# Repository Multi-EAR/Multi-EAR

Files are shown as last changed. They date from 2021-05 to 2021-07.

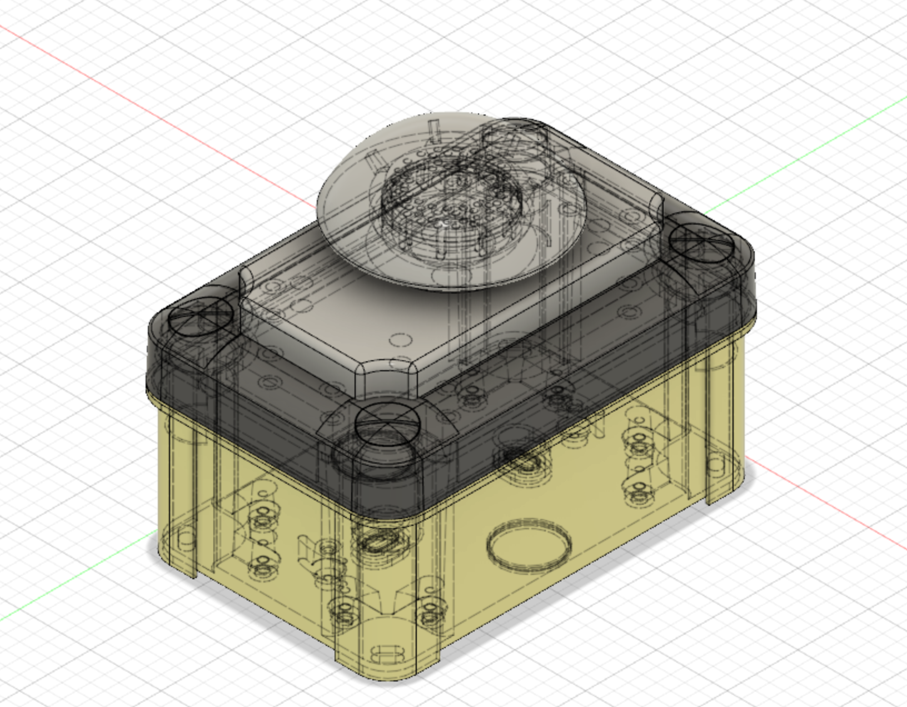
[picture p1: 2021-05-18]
Casing/Small/Small_casing.png

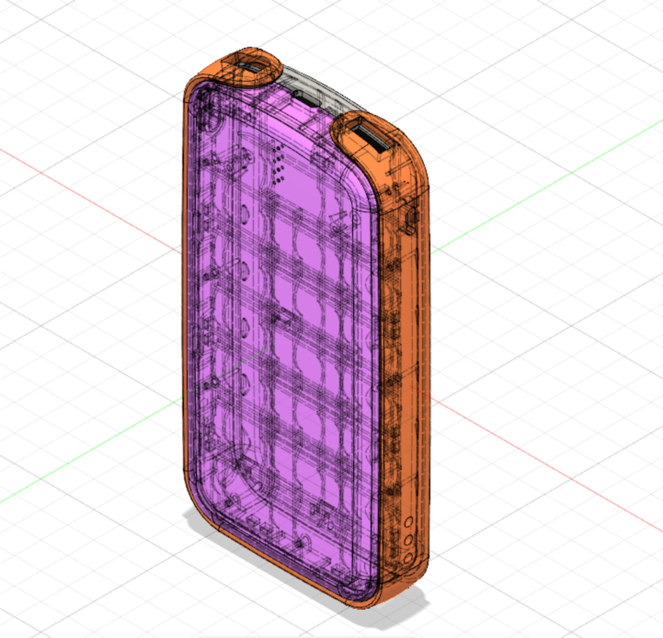
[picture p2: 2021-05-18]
Casing/Solar/V75 Battery/V75.png

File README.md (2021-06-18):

# Multi-EAR

The Multi Earth and Atmospheric data Recorder (Multi-EAR); a mobile low-cost multidiciplinairy sensor platform for scientific monitoring of earth and atmosphere.

<hr/>

A collabarotive project between the Royal Netherlands Meteorological Institute (KNMI) and Delft University of Technology (TU Delft).

<sub><sup>Auke Barnhoorn (TUD), Jens van den Berg (TUD), Olivier den Ouden (KNMI/TUD), Pieter Smets (TUD/KNMI), Laslo Evers (TUD/KNMI), Jelle Assink (KNMI), Elliot Donata (Min. IenW), Gijs Schouwenberg (Min. IenW)</sup></sub>

<hr/>

The project has been awarded the 'Digitaliserings-fonds en Ontwikkeling' research grand by the Netherlands Ministry of Infrastructure and Water Management and an 'Innovation' grand by the Delft University of Technology. 

The Multi-EAR is an extension of the INFRA-EAR (\cite{den2020low}), which is a multidisciplinary sensor platform for the monitoring of geophysical parameters, and specially designed to fit a Wandering Albatros. Such requirements, and thus dimensional restrictions, were not applicable by the design and development of the Multi-EAR. The project aims to develop, based on earlier recommendations, a multidisciplinary mobile sensor platform to complement the existing high-fidelity monitoring network. Due to its digital design, the sensor platform can readily be integrated with existing geophysical data infrastructures and be embedded in geophysical data analysis. The small dimensions and low-cost price per unit allow for unconventional, experimental designs, for example, high-density spatial sampling or deployment on moving measurement platforms. Moreover, such deployments can complement existing high-fidelity geophysical sensor networks. To include the Multi-EAR within existing monitoring networks, a Technology Readiness Level (TRL) of 8 is needed (Figure \ref{fig:8}).

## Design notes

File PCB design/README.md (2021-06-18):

# Mobile platform design
### Circuit design

The platform of the Multi-EAR uses various digital Microelectromechanical sensors (MEMS) embedded on a Printed Circuit Board (PCB). A programmable microcontroller unit, embedded on the PCB, controls the sensor's sampling frequency, establishes the energy supply for the sensors, the data communication, and data storage.

The MEMS on the PCB are; two differential pressure sensor (to monitor infrasound), a 6-axis accelerometer/gyroscope, a 6-axis accelerometer/magnetometer, a barometric pressure sensor, a temperature/humidity sensor, microphones (to monitor audible sound), a GPS for location and timing purposes, and LoRa telecommunication for data exchange.

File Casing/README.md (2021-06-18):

# Casings

The protection of the PCB is done with a weather- and waterproof casing. The GPIO pins connect the RPi and the Multi-EAR. For insurance, they are as well connected by four screws on the corners. The casing exists of a pre-ordered polyethene case with an atmospheric dome on top. The RPi is connected to the casing, by a 3D-printed ground-plate, for direct coupling.

## Atmospheric dome
An atmospheric done is placed on top of the casing, fastened with screws and glue. The dome allows air to flow in and out of the casing, essential for the atmospheric measurements but deducts water to enter the casing. Figure \ref{fig:10} shows the 3D CAD design of the dome. Air can flow into the dome via the inlets on the side and top of the capture. This way, the dome enables airflow inside the casing but obstructs water. Whenever moisture becomes a problem, GoreTex air vents may be considered (\cite{den2020low}). Furthermore, the dome also prevents stagnation pressure, which may mask the differential pressure measurements (\cite{raspet2019new}).
 
## Casing designs
Two different casings are developed for the Multi-EAR (Appendix D). The smaller casing (\cite{SmallCasing})has a dimension of 130 x 85 x 115 mm (Figure \ref{fig:11}). The dome is placed on top of the transparent lid of the casing, while the two antennas are mounted to the side and the external power supply plug. The smaller casings are not fully autonomous, and it does not function without connection to an external power supply. Whenever powered, however, the Multi-EAR starts recording and collecting data, as pre-defined in the firmware.
 
The larger casings have a dimension of 240 x 191 x 130 mm (\cite{LargeCasing}) and includes a solar panel. These casings are designed to make the Multi-EAR completely autonomous. Again a polyethene case with the atmospheric dome on top is used. The GPS and LoRa antenna are connected to the outside of the casing and the ability to use external power.

## Antennae
The LoRa and GPS on the PCB are both connected to external antenna's. The antennae are passive LinX antennae (\cite{Linx}). The band with range is between 617MHz - 5 GHz. The classification of the antenna is a high-blade for optimal signal coverage. 
The polarization of the antennae is linear, and the radiation of signals omnidirectional. Moreover, the GPS on the PCB, and thus the antenna, is a GNSS receiver (\cite{GNS2301}) and thus compatible with GPS (global system), GLONASS (Russian navigational system), Beidou (Chinese navigational system), Galileo (European navigational system). Therefore the PCB has perfect coverage.   
The antennae are mounted to the outside of the casings and connected to the MEMS of the GPS and LoRa by SMA extension cables (\cite{SMAcable}, Appendix D).

## External power supply
5W micro-USB connectors generate the external power supply. The cable is modified to ensure the complete protection of the casing. Moreover, the modification allows disconnecting the power supply from the outside without doing modifications within the casing.
Within the casing, the RPi is connected through Micro-USB with a female Amphenol connector (\cite{Amphenol}, Appendix D). This female connector is pinned to the outside of the casing. The male connector is directly connected to a 5W adaptor. The connection between male and female connectors is strong and weather/waterproof. Figure \ref{fig:pin} shows the 'three-pin layout of the Amphenol connectors.
 
## Autonomous system
The larger casings are equipped with a solar panel (\cite{VoltaicSolar}) and battery pack (\cite{VoltaicBattery}). These platforms can either be powered by an external power supply or by a battery pack. The battery pack is a V75 battery and is placed within the casing. It has an 'always-on mode; it can power, charge, and pass-through charging. The capacity is 19.200 mAh (71 Watt-Hours), and the output is 5V. 

The solar panel that charges the V75 battery pack is placed on top of the casing. The mounting allows modification of sunlight's angle. The panel is waterproof and has a 9Watt, 6V output. 

## Energy analysis

To determine whether the autonomous system can monitor continuously, thorough energy analysis is performed. The energy analysis is divided into (1) the energy consumption by the PCB and RPi during concurrently continuous monitoring and the (2) power supply by the solar panel and battery capacity to survive the evenings.

First, the energy consumption by the RPi. Assuming continuous measurements and thus power supply, the RPi will use approximately 1 Watt per hour, which adds to a maximum of 24 Watt per day. 

The consumption by the PCB depends on the low-energy MEMS sensors, which is marginal compared to other monitoring devices. The power consumption is estimated at around 5W per day, which is 0.2 Watt per hour. 

Therefore, the total power consumption of the entire system is estimated to be approximately 29 Watt per day, which is 1.2 Watt per hour.

The V75 battery pack has a maximum capacity of 71 Watt. Without charging the battery pack, the monitoring system can be active for approximately 70 hours. During summer, the time between sunset and sunlight is approximately 6 hours. Therefore it is assumed the system will 'survive' the summer evenings. In winter, the nights are longer, and therefore the re-charging time of the battery is shorter. Moreover, thus the monitoring system is assumed to run out of power during these periods.

During the day, the battery pack needs to be charged while supplying the needed power for the monitoring system. To determine the expected charging energy of the solar panel, a thorough analysis is performed. For the analysis, the solar panel position is fixed to the Campus of the TU Delft. Based on the technical specifications of the 9 Watt solar panel and the expected sunlight at the Campus, energy analysis is calculated (\cite{SolarEnergy}). Figure \ref{fig:solar} shows the average energy output of the solar panel in Watt per day. Note that from March until September, the Solar panel provides enough power to run the system. Since enough power is provided for the monitoring system, the battery will be charged during the day. Within the winter months, however, the monitoring system will run out of power. The battery and solar panel will not provide sufficient power for continuous and concurrent monitoring.

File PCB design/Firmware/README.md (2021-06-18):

# Firmware

The communication between the microcontroller and MEMS on the PCB is either done by Inter-Integrated Circuit (I2C) or Serial Peripheral Interface (SPI) and depends on the sensor and personal preference. Both communication methods are bus protocols and allow for serial data transfer. However, SPI handles full-duplex communication, simultaneous communication between microcontroller and MEMS sensor, while I2C is half-duplex. Therefore, I2C has the option of clock stretching, and the communication is stopped whenever the MEMS sensor cannot send data. Besides, I2C has built-in features to verify the data communication (e.g., start/stop bit, acknowledgement of data). Although the I2C protocol is favourable, it requires more power. Moreover, the number of I2C ports on the microcontroller is limited. Therefore a mix of both SPI and I2C protocols is needed.

The microcontroller runs on self-made software, complementing the required manufacturers electrical and communication protocols. The software allows determining the sample time, sample frequency, and data storage of selected MEMS. The raw output of the digital MEMS sensors are stored as bits, and the microcontroller performs no data processing to save power consumption. 

The firmware, and thus the data acquisition, can be changed and updated on the microcontroller.

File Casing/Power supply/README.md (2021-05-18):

# External Power supply 

To power the RPi and Multi-EAR with an external power supply, a 5W adapter is used. One half of the adapter cable is soldered to the female amphenol connector, while the other half is soldered to the male amphenol connector. This way the external power supply of the Multi-EAR can be unplugged during storage. The amphenol connectors ensure a waterproof power supply.

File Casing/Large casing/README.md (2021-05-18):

# Small casing

## Bottomplate

## Atmospheric dome

## 3D printer

## External power supply

## Antenna

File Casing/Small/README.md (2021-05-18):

# Small casing

## Bottomplate

## Atmospheric dome

## 3D printer

## External power supply

## Antenna

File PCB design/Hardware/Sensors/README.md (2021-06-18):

# Sensors

## Sound sensors
The human audible sound spectrum is approximately between 20 to 20,000 Hz. Frequencies below 20 Hz or above 20 kHz are referred to as infrasound and ultrasound, respectively. The movement of large air volumes generates infrasound signals with amplitudes in millipascals' range to tens of pascals. Examples of infrasound sources include earthquakes, lightning, meteors, nuclear explosions, interfering oceanic waves and surf (\cite{campus2010worldwide}). Detection of infrasound depends on the signal's strength relative to the noise levels at a remote sensor (array), i.e., the signal-to-noise ratio. The signal strength depends, in turn, on the transmission loss that a signal experiences while propagating from source to receiver (\cite{waxler2019propagation}). Local wind noise conditions predominantly determine the noise (\cite{raspet2019new}), in addition to the sensor self-noise. Due to the presence of atmospheric waveguides and low absorption at the infrasonic frequency (\cite{sutherland2004atmospheric}), infrasonic signals can be detected at long distances from an infrasonic source. Assumed that the source levels are sufficiently high so that the long-range signal is above the ambient noise conditions on the receiver side, and the sensor is sensitive enough to detect the signal.

### Infrasound
The infrasonic wavefield is conventionally measured with pressure transducers since such scalar measurements are relatively easy to perform. Those measurements can either be performed by absolute or differential pressure sensors. An absolute pressure sensor consists of a sealed aneroid and a measuring cavity connected to the atmosphere. A pressure difference within the measuring cavity will deflect the aneroid capsule. The mechanical deflection is converted to a voltage (\cite{haak1996microbarograph}). The measurement principle of a differential infrasound sensor relies on the deflection of a compliant diaphragm, which is mounted on a cavity inside the sensor. The membrane deflects due to a pressure difference inside and outside the microphone, which occurs when a sound wave passes. A pressure equalization vent is part of the design to make the microphone insensitive to slowly varying pressure differences originating from long-period changes in weather conditions (\cite{ponceau2010low}).  

Various studies show sensor self-noise and sensitivity curves of infrasound sensors (\cite{ponceau2010low,merchant2015hyperion,slad2016chaparral,marty2019ims,nief2019new}). The IMS specifications state that the sensor self-noise should be at least 18 dB below the global low noise curves at 1 Hz (\cite{brown2014idc}), generated from global infrasound measurements using the IMS. Typical infrasound sensor networks, such as the IMS, use analogue sensors connected to a separate data logger to convert the measured voltage differences to a digital signal. The sensor's characteristic sensitivity determines the sensor resolution, i.e., the smallest difference that the sensor can detect. The resolution of the built-in analogue-to-digital converters (ADC) and the digitizing voltage range determine the datalogger's resolution. Current state-of-the-art data loggers have a 24-bit resolution. New infrasound sensor techniques involve digital outputs since the ADC conversion is realized inside the sensor (\cite{nief2017new,nief2019new}). 

The design of this instrument is based on the following requirements. The sensor should have a flat, linear response over a wide infrasonic frequency band, e.g., 0.05 - 10 Hz. The sensor should be sensitive to the range of pressure perturbations in this frequency band, ranging from millipascals to tens of pascals. Moreover, the sensor and logging components' self-noise should be below the ambient noise levels of the IMS (\cite{brown2014idc}). Taking this into account, the sensor requires as well to be low-cost (i.e., tens of dollars), small in dimensions (i.e., millimeter), and have a low energy consumption (i.e., milliampere). 

The measurement principle relies on the deflection of a diaphragm, which is mounted between two inlets. One inlet is connected to the atmosphere, while the other is connected to a cavity. The digital MEMS DLVR-F50D differential pressure sensor from All Sensors Inc (\cite{DLVR}) is used as a sensing element within the mini-MB. This sensor has a 16.5mm x 13.0mm x 7.3mm dimension and a linear response between $\pm$ 125 Pa and a maximum error band of $\pm 0.7$ Pa. A Wheatstone bridge senses the diaphragm's deflection by measuring the changes in the piezo-resistive elements attached to the diaphragm. The sensor's output is an analogue voltage, which is subsequently digitized by the built-in 14-bit ADC, offering a maximum resolution of $0.02$ Pa/count.

### Audible sound
For the monitoring of the audible sound spectrum, three ICS-40300 microphones are embedded on the PCB (\cite{ICS40300}). These microphones are low-noise, high SPL MEMS microphones with an extended low-frequency response. The frequency response can be extended from $6-20\text{k}$ Hz and has a flat response between $50-2500$ Hz. Thanks to this frequency range, combining the infrasound sensor and the microphones results in an excellent phase and amplitude characteristic within a broad frequency range (0.075 - 20k Hz). The maximum SPL level of the microphones is 130dB before the overload is reached. 

The measurements of the microphones are by default stored as RMS dB SPL level over the entire frequency range. Whenever an RPi is used as a datalogger, there is an option to store the entire time series recording.

## Meteorological sensors
The detectability of infrasound is directly linked to wind noise conditions and the atmosphere's stability in the infrasound sensor's surrounding since noise levels are increased when turbulence levels are high. Therefore, it is beneficial to have simultaneous measurements of the basic meteorological parameters, i.e., pressure, humidity and temperature. The sub-sections below describe the different meteorological measurements contained on the sensor platform.

### Barometer
The barometric pressure is sensed by the LPS33HW sensor (\cite{LPS33HW}). The measuring principle relies on piezo-resistive crystals. The atmospheric pressure applies a force to the sensor, which causes the crystals to vibrate. Whenever piezo-resisitve crystals have contact, or a force is applied to the, a small voltage is released.

The sensor design is analoge, using voltages to derive the geophysical units. However, this MEMS has an in-built 14-bits ADC. The ADC bits and the precision of the crystals determine the self-noise of the sensor. Whenever the self-noise is higher as the actual change in atmospheric pressure, it will not be resolved by the sensor. The manufacturer states that the relative error of the sensor is $\pm 0.1$hPa. However, the absolute error can be larger. Therefore a calibration need to be performed on these sensors, to remove the absolute error. \cite{den2020low} stated that after calibration the sensor can indeed have an accuracy of $\pm 0.1$ hPa.

### Temperature/Humidity
The SHT8x sensor measures the temperature and humidity at the PCB (\cite{SHT8x}). The SHT8x is a temperature and humidity sensor with a pin-type connector. This connector allows easy integration and replacement of the sensor. Furthermore, it allows for the best possible thermal coupling to the environment and decoupling from potential heat sources on the PCB. The sensing is done by the SHT3x sensor, which is part of the SHT8x set-up. The SHT8x has an in-built 16-bit ADC.

The humidity is sensed over the range of $0-100\pm$. The SHT3x has a resolution of $0.01 \pm$, with a relative error of $1.5 \pm$. The absolute error needs to be determined by calibration.

The operating range of the temperature sensor is between $-40 - 105^{\circ}$C. The resolution is $0.01^{\circ}$C, with a relative error of $0.3^{\circ}$C while operating over the entire temperature range.

## Inertial measurement units
The sensing element of the infrasound sensor on this platform is a sensitive diaphragm. Strong accelerations of the platform will cause a deflection of the diaphragm and may obscure infrasonic signal levels. In addition, such accelerations may be misinterpreted as infrasound if no independent accelerometer information is available. To be able to separate the mechanical response of the sensor from actual signals of interest, the platform measures accelerations for which the LSM303 (\cite{LSM303}), a 6-axis inertial measurement unit, and LIS3DH (\cite{LIS3DH}), as well a 6-axis inertial measurement unit, are deployed. The LSM303 consists of a 3-axis accelerometer and 3-axis magnetometer. The LIS3DH is a 3-axis accelerometer and 3-axis gyroscope. The measurement range of both accelerometers varies between 2-16 g.

Accelerometers measure differential movement between the gravitational field vector and its reference frame. In the absence of linear acceleration, the sensor measures the rotated gravitational field vector, which can be used to calibrate the sensor. A rotational movement of the sensor will result in acceleration. Both MEMS are digital sensor with built-in ADC's of 16-bit. This results in a resolution of 0.06 mg when choosing the lowest measurement range.

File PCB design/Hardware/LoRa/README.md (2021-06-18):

# LoRa Telecommunication
Besides transferring data via the RPi and WiFi, the data can also be transferred by LoRa Telecommunication (\cite{LoRa}). LoRa is a type of wireless telecommunication vast area network designed to allow long-range communications at a low bit rate among things (connected objects). The low power, low bit rate and intended use distinguish this type of network from a wireless WAN designed to connect users or businesses and carry more data, using more power. The LoRa data rate ranges from 0.3 kbit/s to 50 kbit/s per channel. LoRa may be used to create a private wireless sensor network but may also be a service or infrastructure offered by a third party, allowing the owners of sensors to deploy them in the field without investing in gateway technology.

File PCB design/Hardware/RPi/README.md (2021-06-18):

# Raspberry Pi - external datalogger
The microcontroller communicates in two ways with the MEMS. After sampling, the MEMS send their data back to the microcontroller. The data can either be stored locally on the PCB, using a micro-SD card, or sent through UART serial communication. The PCB embeds GPIO pins, which allow UART communication. The GPIO allows a connection between the PCB and a Raspberry Pi (RPi, \cite{RPi}), and thus the data communication between both. The RPi can therefore act as a small datalogger. The RPi receives on a pre-specified baud-rate the data in bytes, when after the data can either be formatted to floats, integer, or actual units, before sending it to the server (Appendix B).

The RPi is a small single-board computer and has all the usual connections (i.e., HDMI, USB, Micro-USB). The operating system on the RPi's of the Multi-EAR is 'raspbian-lite' and can connect with WiFi. The data can be transferred towards an external device via WiFi or an SSH connection (Appendix C).

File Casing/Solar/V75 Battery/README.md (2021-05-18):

# V75 battery pack of Voltaic

For up-to-date specs, check; https://voltaicsystems.com/v75/

## Size and Weight
* 15.1 x 7.8 x 2.6 cm
* 382 grams
* Capacity: 19,200mAh, 71 Watt Hours
* Output: 5V/2A , 3A max (2 outputs)
* MicroUSB Input: 5-6V/2A
* USB-C (Input Only): 5V/2A
* Battery Type: Li-Ion
* Protection: Short circuit over charge, over discharge, over temperature (35℃ Input Cutoff, 45℃ Output Cutoff), under temperature (0℃ Input Cutoff, -20℃ Output Cutoff)

## Always On Mode
Battery features updated Always On technology as its standard state and will not shut off even if your device is drawing low or no power. There is no low current cutoff.

To stop charging your device, double tap the Power Level Button or disconnect from the battery. To resume charging, tap the Power Level Button once.

Battery recovers into Always On mode after discharge, over-temperature and under-temperature events. Power consumption in Always On mode is approximately 7mA.

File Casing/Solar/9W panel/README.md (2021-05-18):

# Voltaic systems 9W, 6V Solar panel specification

For the up-to-date specifications, check: https://voltaicsystems.com/9-watt-panel/ 

## Features
* Waterproof (IP67)
* UV resistant (10+ year life)
* Durable and lightweight
* High efficiency monocrystalline cells: 19%
* Embedded screws for easy mounting
* ABS plastic post nuts included (4x)

## Size and Weight
* 22.1 x 25.7 x 0.5 cm
* 357 grams

## Output
* Open Circuit Voltage: 7.7V
* Peak Voltage: 6.5V
* Peak Current: 1,420mA
* Peak Power: 9.2W
* Power Tolerance: +/-10%
* For maximum power output, orient the panel towards the sun

## Construction
* Urethane coating
* 3mm aluminum-plastic composite substrate

## Mounting
* Four embedded screws: 4-40 thread, 0.46 cm long
* Attach to a vertical pole using Universal Panel Bracket
* Attach to a metal surface using magnet mounts

## Output Cable
* Cable Length: 26 cm
* Cable Color: Red PU Coated
* Plug: Waterproof Male 3.5x1.1mm
* Extend the cable length using 1 foot, 4 foot, and 10 foot extension cables
* Solder directly to a PCB using extension with exposed leads

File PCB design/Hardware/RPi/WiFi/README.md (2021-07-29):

# Connecting the Multi-EAR to a local network.

Connecting the sensor platform to a local WiFi network can be done in various ways. The information of the known WiFi networks is stored on the Raspberry Pi (RPi).  Within the folder “/etc/wpa_supplicant/“ the file “wpa_supplicant.conf” is stored. This is the WiFi information file. There are two, relatively easy ways, to update this file with a new WiFi network. This is either one (1) directly on the SD-card or (2) via an external connection od the RPi to a laptop.

## (1) Direct update on SD-card

Eject the SD-card from the RPi, and put it in the SD-card reader of your computer. Within the computer folder an external volume is detected: “boot”. This is the boot file of the RPi, which is used every time the RPi is booted. Within this boot file you “simply” paste the example “wpa_supplicant.conf” file from this GitHub page. **NOTE! You have to update this “wpa_supplicant.conf” file with the details of the local (or university) WiFi network!**

Whenever you have pasted this file to the boot volume, you can safely eject the SD-card from your computer. Insert the SD-card back into the RPi, whenever the RPi is booted the WiFi wpa_supplicant file is update with the new network information.

Knowledge about the IP-adres of the RPi on your local network can be obtained from the “Fing” app, which is available in the Apple App-store. This app allows to detect all devices on your local network, and their IP-adres. If you correctly followed the steps the RPi will show up within this list of devices connected to your network.

Thanks to a pre-check the RPi is enabled to acces via SSH. This can be done via Putty (Windows) or the Terminal (UNIX/Mac). 

## (2) External connection with computer 
**NOTE! First remove the Multi-EAR extension PCB!** 

A different approach is by connecting the RPi with a MicroSD-USB cable to your computer. The RPi is booted thanks to the power supply form the computer. Again via Putty or the Terminal you can now directly SSH towards the RPi. This is done by using the local IP adres:
	raspberrypi.local

Now you have entered the RPi, and you are able to update the “wpa_supplicant.conf”. 

Enter: “sudo nano /etc/wpa_supplicant/wpa_supplicant.conf“
Add the information of your local network (as shown within the example)
Exit the file, and reboot the system

To detect the IP-adres you can either use the “Fing” app, or: 
SSH again via: “raspberry.local”
Enter: “ifconfig” and readout the IP-adres.

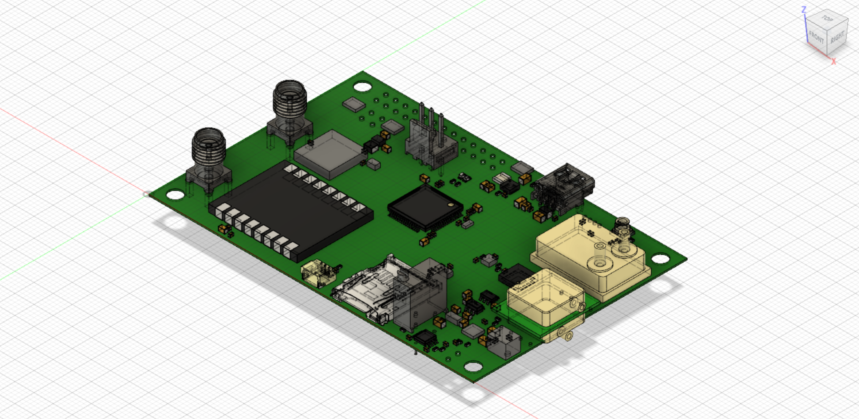
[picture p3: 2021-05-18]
PCB design/Hardware/PCB/Multi-EAR.png

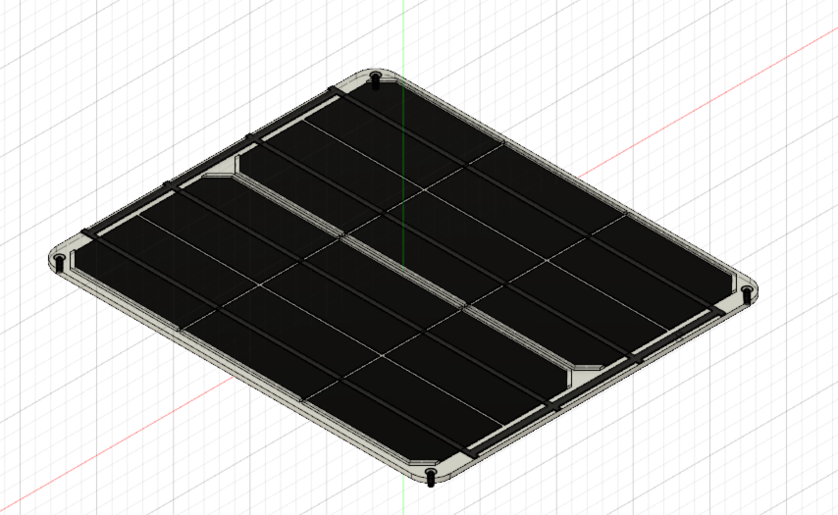
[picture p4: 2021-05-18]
Casing/Solar/9W panel/9W, 6V Solar PNG.png

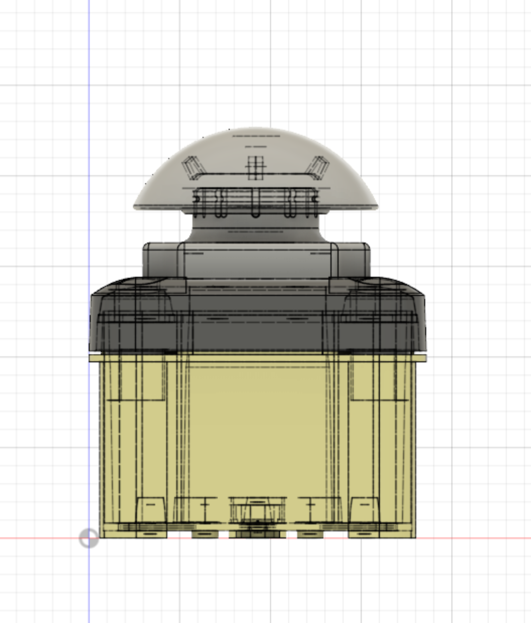
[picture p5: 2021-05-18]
Casing/Small/small_side_1.png

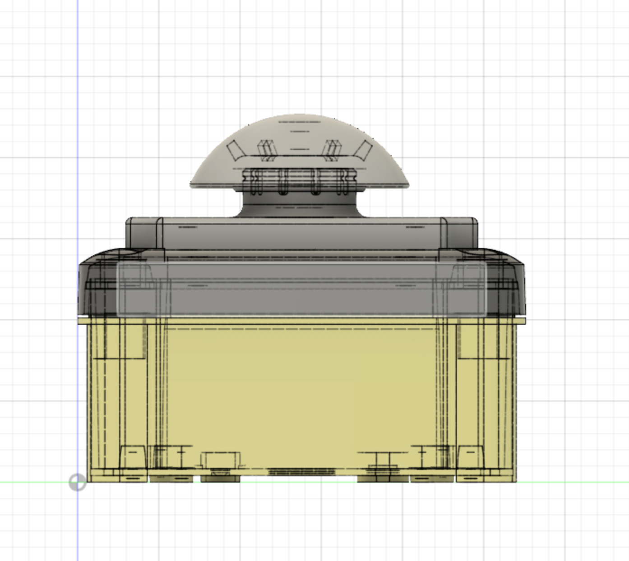
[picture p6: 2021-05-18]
Casing/Small/small_side_2.png

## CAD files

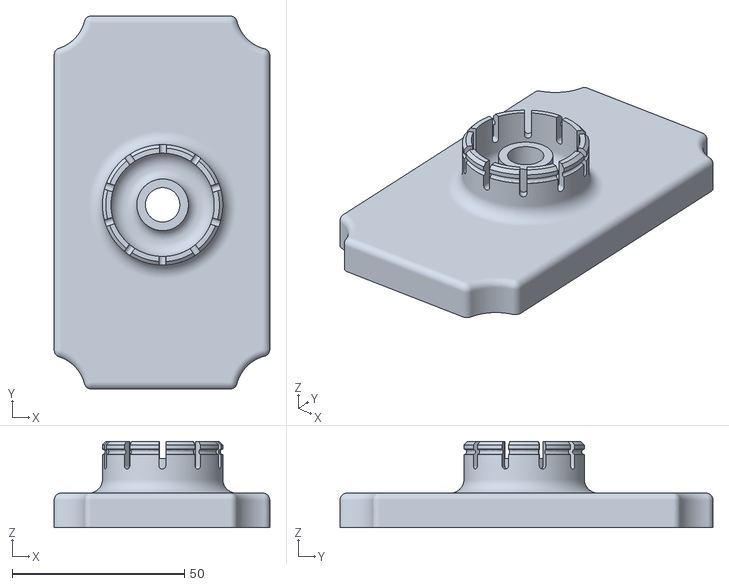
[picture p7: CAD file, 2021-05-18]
Casing/Dome/solarpannel mount baseplate.stl
62.7 x 108.4 x 25.0

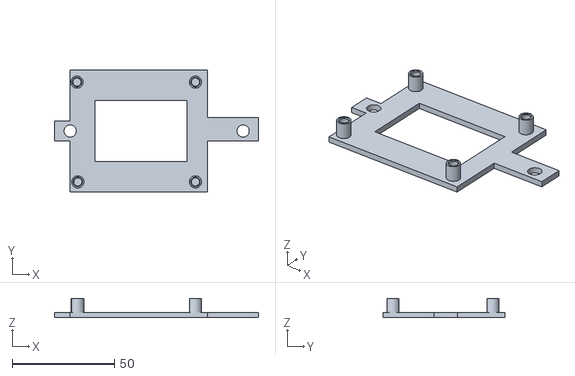
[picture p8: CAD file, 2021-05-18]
Casing/Small/2ebottem v9.stl
99.9 x 60.0 x 9.50

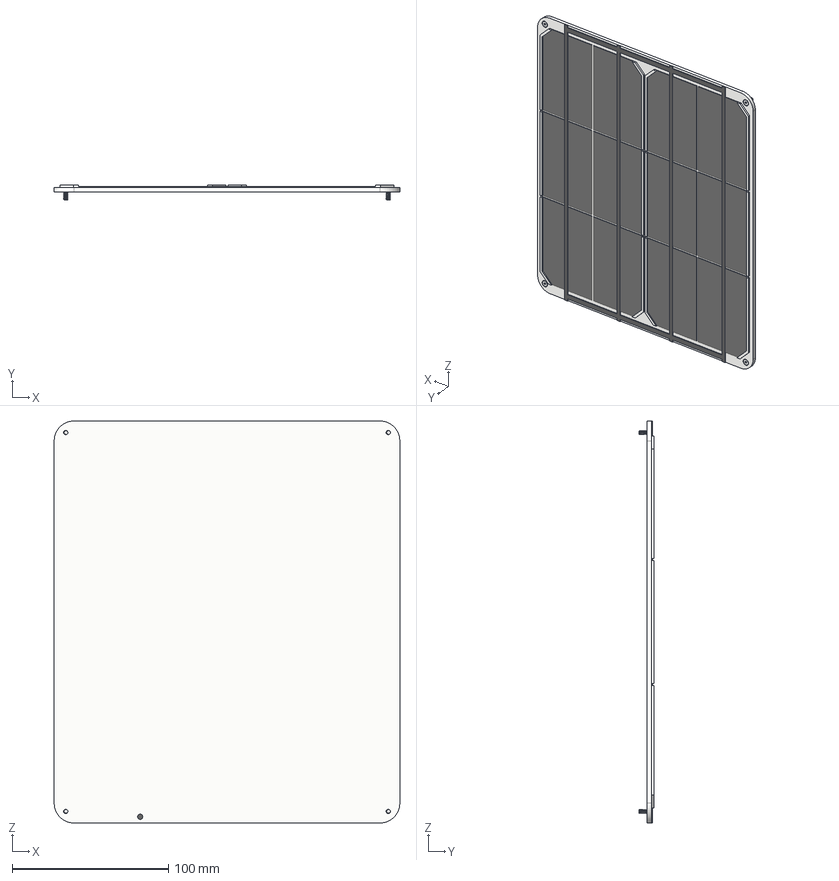
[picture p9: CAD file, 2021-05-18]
Casing/Solar/9W panel/9W 6V 221x257mm Voltaic Panel.step
221.0 x 9.40 x 257.0 mm

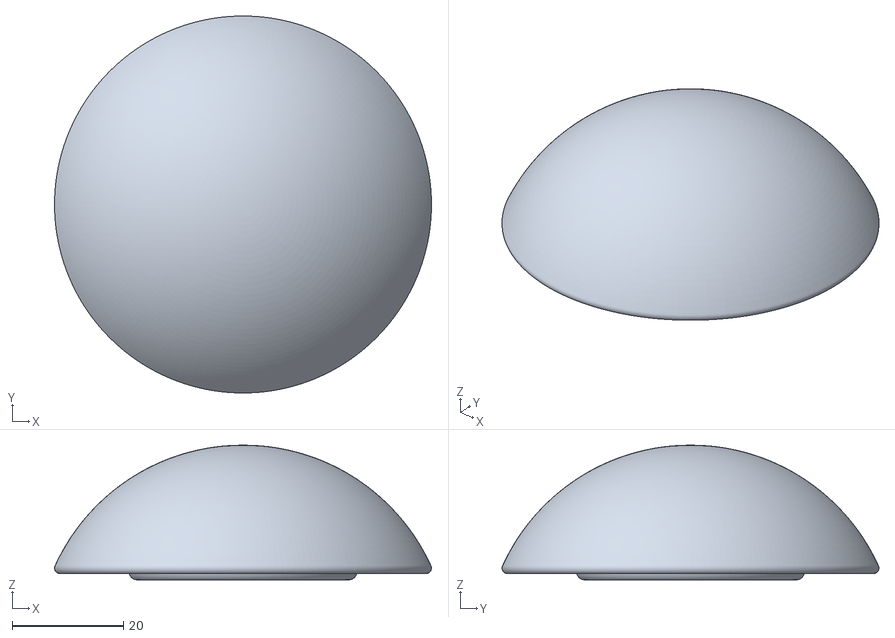
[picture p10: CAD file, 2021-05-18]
Casing/Dome/regen afscherming.stl
67.8 x 67.8 x 24.2

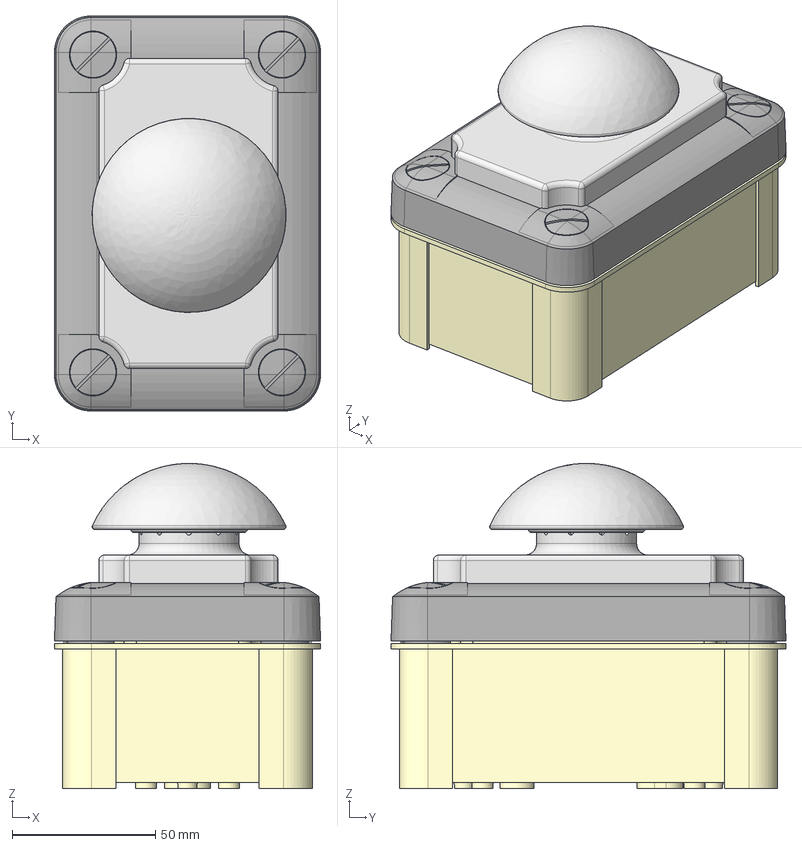
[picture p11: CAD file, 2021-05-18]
Casing/Small/samenstelling.stp
93.0 x 138.0 x 113.6 mm
box_nsytbp1397t_01
box_nsytbp1397t_02
solarpannel mount baseplate
regen afscherming

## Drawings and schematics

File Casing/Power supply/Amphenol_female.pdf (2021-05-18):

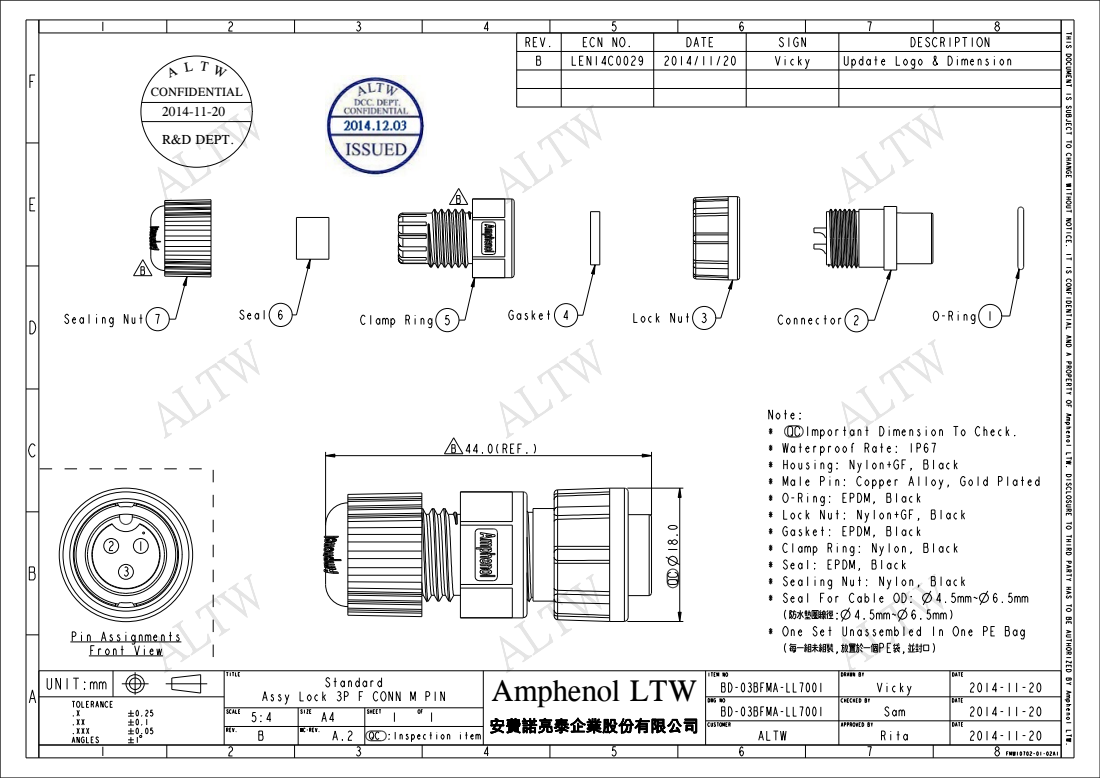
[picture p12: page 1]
Amphenol LTW; CONFIDENTIAL; R&D DEPT.

ALTW ALTW ALTW

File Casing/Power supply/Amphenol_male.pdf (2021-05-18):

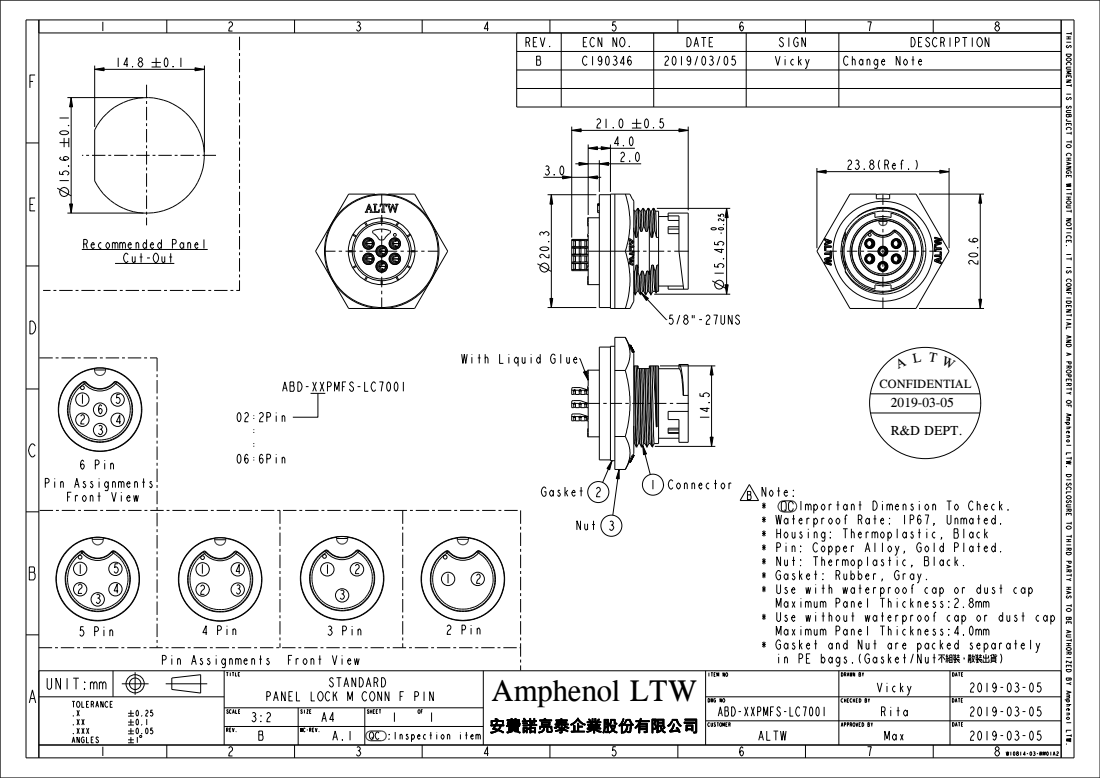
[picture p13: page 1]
Amphenol LTW; CONFIDENTIAL; R&D DEPT.

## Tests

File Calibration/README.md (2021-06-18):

# Sensor calibration

The sensor calibration and comparison have been performed according to the KNMI-calibration standards within the KNMI calibration lab. Besides lab calibrations, the sensor platform has also been placed on the KNMI test field, enabling a comparison of the platform with high-fidelity equipment.

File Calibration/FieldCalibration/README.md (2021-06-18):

# Field calibration

The field tests of the monitoring platform have been performed within building K of the KNMI. This building is placed at the border of the KNMI test field. Building K is a shelter and provides an energy supply for the monitoring system. However, for direct and correct comparison between the meteorological MEMS with the KNMI sensor network, it is recommended to perform future comparisons outside building K. The remainder of geophysical parameters are correctly sensed from building K.

## Meteorological observations
The LPS sensor has been field-tested (Figure \ref{fig:5}-a), along with a Paroscientific Digiquartz 1015A barometer, which has an accuracy of 0.05 hPa. Figure \ref{fig:fieldBaro} shows the comparison between the Mulit-EAR (red line) and the baroemtric reference sensor (black line). It stands out that both sensors resolve the changing barometric pressure. From the distribution of observations, it has been estimated that the LPS sensor has a precision of $\pm 0.1$ hPa for $87\%$ of the time. For the remainder, the maximum deviation was $\pm 0.2$ hPa. 

The comparison between the Multi-EAR's temperature has been performed with the reference sensor xx. This sensor has an accuracy of xx. Figure \ref{fig:fieldtemp}-a shows the comparisons between both. Not that the maximum temperature is correctly resolved by the Mulit-EAR. The minimum temperatures (occurring during the night), however, are not correctly resolved. This is due to the monitoring circumstances, building K conserves the 'day-warmth'.

The same phenomena occurs with the humidity sensor. The humidity within building K is continuously below the actual meteorological humidity. Therefore a correct comparison between the Multi-EAR's humidity sensor and the KNMI reference sensor can not be performed. 
 
## Sound observations

## Movement observations

Within \cite{den2020low} a comparison test has been carried out in the seismic pavilion of the KNMI. Inside this pavilion, the LSM accelerometers has been compared to a Streckeisen STS-2 seismometer connected to a Quanterra Q330, as a reference sensor \cite{knmi:1993}. Both sensors were installed on pillars, to ensure a good coupling between the subsurface and the sensor. The comparison test, which was based on 24 hours of recording, shows that the accuracy of the LSM303 3-axis accelerometer is $\pm1.5$ mg ($1.5 \text{ cm/s}^{2}$). While the sensors are deployed on the same seismic pillar and are thus subject to similar seismic noise conditions, the MEMS sensor could not measure ambient seismic noise (\cite{peterson1993observations,mcnamara2004ambient}) due to its high self-noise level. The LSM accelerometer exceeds both the U.S. Geological Survey New High Noise Model (NHNM) (\cite{peterson1993observations}) and the STS-2 reference sensor by at least 35 dB.

For the comparison between the two accelerometers on the Multi-EAR the z-components of both sensors has been used. The full recordings are divided into hourly recoridngs, which are used to calculate PSD's. The reference sensor in the seismic paviljoen confirms no major seismic activity has been recorded. Therefore, only ambient seismic noise is expected within the MEMS recordings. 

Figure \ref{fig:Accl} shows the stacked PSD's for the LSM (panel a) and LIS (panel b) MEMS sensors. The solid gray lines indicate the high and low ambient seismic noise curves (\cite{peterson1993observations,mcnamara2004ambient}). It is shown that both MEMS have a self-noise higher as the ambient seimsic noise. The MEMS, therefore, can not resolve these noise levels. Note that the self-noise levels of the MEMS is not equal. The LIS has a lower self-noise as the LSM, while the ADC has the same amount of bits (\cite{sleeman2006three}). However, ADC's are sometimes suffering a 'loss of bits' due to power supply. Whenever the efficiency of the MEMS not optimal, this may lead to less power supply towards the ADC, and thus a loss of bits. The LIS sensor is a accelerometer and gyroscope, whereas the LSM is an accelerometer and magnetometer. The combination may influence the efficiency of power towards the ADC, which explains the different self-noise levels.

Furthermore, the dotted black lines within both panels indicate the expected amplitude levels of earthquakes with an approximate distance of 10km (nearby transient sources) [cite raspberry shake manual]. Based on these levels it is highly expected that both MEMS will record a nearby transient event. 

Based on these plots, it is unlikely to use both MEMS for monitoring purposes of ambient seismic noise or teleseismic events. Previous studies drew similar conclusions concerning the performance of MEMS accelerometers. Various calibration set-ups are considered while comparing MEMS accelerometers with conventional accelerometers of geophones (\cite{hons2008field,albarbar2009performance,anthony2019low}), each concluding that the accuracy of the MEMS is not sufficient for recording ambient seismic noise. However, strong local events or boisterous environments the MEMS sensor will resolve those seismic signals.

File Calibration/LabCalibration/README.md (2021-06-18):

# Lab calibration

## Barometric pressure
Calibration tests on the barometric pressure sensor are performed within a pressure chamber, in which a cycle of static pressures between 930 and 1070 hPa can be produced. Besides the MEMS sensor, the chamber is equipped with a reference sensor. This procedure resulted in a calibration curve, which describes the pressure-dependent systematic bias. After correcting for the bias, the LPS sensor has an accuracy of $\pm$ 0.1 hPa, i.e., the LPS sensors measures values within $\pm$ 0.1 hPa of the value measured by the KNMI reference sensor. 

## Temperature/Humidity
The calibration tests on the temperature and humidity sensor are performed within the climate chamber. The climate chamber is a certified calibration tool, which can generate temperatures between $-30$ till $50^{\circ}$C and a humidity level (depending on the temperature) between $10-90 \pm$. Within the chamber, various reference sensors are placed. Again, the calibration results in a calibration curve, which describes the temperature/humidity dependent bias. After the bias correction, the temperature sensor has an accuracy of xxx.

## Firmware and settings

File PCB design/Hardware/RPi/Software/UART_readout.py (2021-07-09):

import time
from time import sleep
import serial
import datetime
import os
#ser = serial.Serial("/dev/ttyS0", baudrate = 119047, parity=serial.PARITY_NONE)
sleep(30)
time_start = datetime.datetime.utcnow()
#time_start = time_start.timestamp()
os.mkdir('/home/pi/Data/data_'+str(time_start))

ser = serial.Serial("/dev/ttyS0", baudrate = 115200)

count=0
while True:

    if count==0:
        time_now = datetime.datetime.utcnow()
        time_now = time_now.timestamp()
       
        f = open("/home/pi/Data/data_"+str(time_start)+"/data_"+str(int(time_now))+".log","wb")

    rx_data = ser.readline()
    sleep(0.2)
    data_left = ser.inWaiting()
    rx_data += ser.read(data_left)
    
    f.write(rx_data)

    count=count+1

    if count==180:
        f.close()
        count=0

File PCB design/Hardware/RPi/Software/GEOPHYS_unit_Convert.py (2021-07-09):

#import numpy as np

#data = open('data_2.txt', 'r')

with open('data_1625816225.log', 'rb') as f2:
	data = f2.read()
	for i in range(0,len(data)-2):
		if data[i] == 17 and data[i+1] == 153 and data[i+2] == 34 and data[i+3] == 136 and data [i+4] == 51 and data[i+5] == 115:
			#print(data[i:i+60])
			n_bytes = data[i+10]
			pay_load = data[i+11:i+11+n_bytes]
			print(len(pay_load))
			
			for n in [0,4,6,8,11,20]:
#,15,21,27]:
#,23,25,27,29]:
				if n==0:
					hour = float(pay_load[n])
					min  = float(pay_load[n+1])
					sec  = float(pay_load[n+2])
					mult = float(pay_load[n+3])
					print(hour,min,sec,mult)
				elif n==4:
					DLVR = pay_load[n]
					DLVR|= pay_load[n+1]
					pDLVR = float(DLVR)
					pDLVR*= 0.01*250.0/6553.0
					print(pDLVR)
				
				elif n==6:
					SP210 = (pay_load[n])<<8
					SP210|= pay_load[n+1]
					pSP210 = float(SP210)
					pSP210 = pSP210*1.0/(0.9*32768.0)
					pSP210 = pSP210*250
					print(pSP210)

				elif n==8:
					LPS = (pay_load[n])+(pay_load[n+1]<<8)+(pay_load[n+2]<<16)
					pLPS= float(LPS)
					pLPS/=4096.0
					print(pLPS)

				elif n==11:
					LIS3_x = pay_load[n]
					LIS3_x|= pay_load[n+1]
					pLIS_x = float(LIS3_x)
					pLIS_x*=0.076

					LIS3_y = pay_load[n+2]
					LIS3_y|= pay_load[n+3]
					pLIS_y = float(LIS3_y)
					pLIS_y*=0.076

					LIS3_z = pay_load[n+4]
					LIS3_z|= pay_load[n+5]
					pLIS_z = float(LIS3_z)
					pLIS_z*=0.076
					print(pLIS_x,pLIS_y,pLIS_z)
				elif n==160:
					LSM_x = pay_load[n]
					LSM_y = pay_load[n+1]
					LSM_z = pay_load[n+2]

				elif n==20:
					SHT_t = (pay_load[n])<<8
					SHT_t|= pay_load[n+1]
					pSHT_t = float(SHT_t)
					pSHT_t = -45+(175*pSHT_t/65535.0)

					SHT_h = (pay_load[n+2])<<8
					SHT_h|= pay_load[n+3]
					pSHT_h = float(SHT_h)
					pSHT_h*= 100.0/65535.0
					
					print(pSHT_t,pSHT_h)
				#print(float(pay_load[n]))
			#print(float(pay_load[5]))
			#for n in range(0,n_bytes):
				

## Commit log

2021-05-18 STL file of the dome
    [regen afscherming.stl]
2021-05-18 Add files via upload
    STL file of casing mount Dome
    [solarpannel mount baseplate.stl]
2021-05-18 STEP file small casing + dome
    [samenstelling.stp]
2021-05-18 9W, 6V solar panel Voltaic STEP file
    [9W 6V 221x257mm Voltaic Panel.step]
2021-05-18 STEP file of the V75 battery pack
2021-05-18 STEP file bottom casing to RPi
    [2ebottem v9.stl]
2021-07-09 UART read_out file
    The script is "plug-and-play". Whenever the RPi is powered up, the software is boot following the "rc.local" file. Within the "rc.local" file, the python script to read out the UART serial communicat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
    The script starts by creating a data folder within "/home/pi/Data" with the UTC datetime in the name of the folder. Data is stored in memory, every 3 minutes a log file is created within the data fol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
